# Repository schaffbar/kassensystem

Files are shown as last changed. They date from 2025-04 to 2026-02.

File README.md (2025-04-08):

# Kassensystem

## Projektbeschreibung

Dies ist die Geschichte für die Entwicklung eines Abrechnungssystems für die SchaffBar,
einer offenen Werkstatt. Es sollen die Anwesenheiten der Besucher als die Nutzungszeiten
für ausgewählte elektrische Geräte zu Abrechnungszwecken erfasst werden.

Mittels eines RFID-Tags, das dem Besucher ausgehändigt wird, bei der Registrierung an der Theke,
wird beim Betreten und Verlassen des Werkstattbereichs ein Zeitpaar bestimmt,
das zur Abrechnung im Kassensystem herangezogen wird.
An einem Gerät kann mittels des RFID-Tags und einem WLan-Relais die Versorgungsspannung
eines Gerätes ein und ausgeschlatet werden und damit ebenfalls ein weiteres Zeitpaar
erstellt werden, das zur Abrechnung verwendet werden kann.

Das Lesen der RFID-Tags kann mittels eines RFID-Lesers erfolgen,
während die Daten in einer Datenbank auf einem Server gespeichert werden.

Daraus ergibt sich für das System folgende Aufteilung
- rfidReader - Bereitstellung des RFID-Tags an unterschiedlichen Positionen
- Comm Edge Device (TimeMachine) - Software auf dem Server dient als Schnittstelle zum Datenbanksystem
- ein Kassensystem

Als Kassensystem wird aktuell mit einer Offline Version von Odoo gearbeitet,
diese läuft in einem Docker-Container, in einem weiteren Container befindet sich die Datenbank,
ein weiteren Container wird es für die TimeMachine-Software geben.

## rfidReader

An folgenden oben beschriebenen Position kann ein RFID-Reader zur Anwendung kommen.
- dem Tresen
- dem Eingangsbereich zur Werkstatt
- an einem elektrischem Gerät "Gerätekontrolle"
diese Anwendungsfälle werden im weiteren Verlauf auch UseCases genannt.

Aktuell wird die ArduinoIDE zur Entwicklung verwendet, um aber die verwendeten Bibliotheken mitzuliefern
soll die Entwicklung auf PlatformIO umgestellt werden.
Auch soll die LVGL Bibliothek zukünftig verwendet werden, damit später das Handling von Schaltflächen und
anderem leichter implementiert werden kann.

### Hardwarebeschreibung

Eine Mikroprozessorsystem soll folgende Hardwaremerkmale aufweisen.
- ein Mikroprozessor mit einer WLan-Schnittstelle zur Kommunikation mit dem Server und den Datenbanken,
- einem RFID-Modul zum Lesen der ID-Nummer
- ein Display zur Darstellung von Informationen an den Benutzer,
   beziehungsweise Interaktion über die Touch-Funktionalität.

### Softwarebeschreibung

### Konfigurationsdaten

Um den Konfigurationsaufwand gering zuhalten wird beim Start des RFID-Readers die MAC-Adresse an den Server gesendet,
und anhand der Einträge in der Datenbank werden die Konfigurationsdaten an den RFID-Reader übertragen.

#### Tresen

Nach dem Auflegen des RFID-Tags auf dem RFID-Reader wird diese an den Server übertragen und in einer Datensatz der Datenbank abgelegt und steht zur weiteren Verarbeitung am Tresen zur Verfügung, wie Bearbeitung der Besucherdaten, zur Abrechnung, oder ...
Am Tresen erfolgt die Zuordnung des RFID-Tags zu einem Besucher

#### Eingangsbereich

Durch die Registrierung des Besuchers an der Theke hat dieser einen RFID-Tag erhalten, im Anschluss kann er seine Sachen richten, die er mit in den Werkstattbereich nehmen möchte. Beim Betreten und Verlassen des Werkstattbereichs hält der Besucher sein RFID-Tag an den RFID-Leser zur Erstellung einer Zeitmarke, die Differenz der Zeitspanne entspricht der Nutzungsdauer zur Abrechung. In Abhängigkeit der vorhandenen Datenbankeinträge ergibt sich das Betreten bzw. Verlassen der Werkstatt. Zur Berücksichtigung von Pausen oder ähnlichem können in der Datenbank mehrere Zeitpaare
eines Besuchers angelegt werden.

#### Gerätekontrolle

In den Stammdaten eines Besuchers ist hinterlegt, ob für einen Kunden die jeweilige Unterweisung für das Gerät erfolgt ist,
damit kann die unberechtige Verwendung von Geräten verhindert und die Unfallgefahr reduziert werden.
Nur wenn die Unterweisung hinterlegt ist, darf die Versorgungsspannung eingeschaltet werden, auch hier erfolgt die Abfrage
über die die Software auf dem Server.

## Comm Edge Device --Namensfindung

Diese Software bildet das Bindeglied zwischen den RFID-Reader und der Datenbank,
in Abhängigkeit des UseCases und dem Ergebnis der Datenbankabfrage wird die entsprechende Ausgabe auf dem RFID-Reader gessteuert.

## Kassensystem-SW

Aktuell soll eine offline Version von Odoo als Kassensystem verwendet werden,
da hier viele Funktionen bereits vorhanden sind.
Die Kopplung der RFID-Reader an das Kassensystem sowie die Auswertung der zusätzlichen Informationen
aus den hinzugefügten Tabellen muss noch erfolgen.

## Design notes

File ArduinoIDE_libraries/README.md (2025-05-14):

# Compilation der rfidReader SW mit der Arduino IDE

Hier werden einige Schritte genannt um die Software der rfidReader mittels der Arduino IDE 
zu übersetzen und auf den Prozessor zu flashen

## Installation der Arduino IDE

Die Ardunio IDE kann unter dem genannten Link für veschiedene Betriebssystem heruntergeladen werden.
https://www.arduino.cc/en/software/

## Verwendung des ESP32 in der Arduino IDE

Um ESP32 Prozessoren in der Arduino ESP nutzen zu können, sind die Schritte von einer der 
Anleitungen hinter den folgenden Links abzuarbeiten.

https://randomnerdtutorials.com/installing-esp32-arduino-ide-2-0/

https://randomnerdtutorials.com/installing-the-esp32-board-in-arduino-ide-windows-instructions/

## Bereitstellung der verwendeten Bibliotheken

Um die hier verwendeten Bibliotheken mit den zugehörigen weiteren Abhängigkeiten
nicht mühsam einzeln suchen zu müssen werden diese hier bereit gestellt.

Wenn man die Arduino IDE startet kann man unter dem Menüpunkt "File/ Preferences" 
das Fenster für die Einstellungen öffnen. Hinter dem Eintrag unter "Sketchbook location"
gibt es einen Ordner libraries, in diesen sind die hier abgelegten Bibliotheken zu kopieren

## Einstellungen

Unter dem Menüeintrag "Tools/Board" öffnet sich ein Menü, hier ist der Eintrag "ESP32C3 Dev Module" auszuwählen.
Für das Flashen und die Einstellungen der seriellen Schnittstelle ist der Menüeintrag "Port" zu wählen.

## Datum
Diese Datei mit den genannten Links wurde am 09.05.2025 erstellt.

## Sonstiges
Die jeweiligen Nutzungsbdingungen sind unter den originalen Ablageorten zu finden.

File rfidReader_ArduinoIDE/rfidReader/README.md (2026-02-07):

# Setup
## Arduino IDE
- Folge dieser Anleitung um die ESP Platform in der Arduino IDE zu aktivieren: https://docs.espressif.com/projects/arduino-esp32/en/latest/installing.html
- Installiere die fehlenden Bibliotheken.
- Board: ESP32C3
- USB CDC On Boot: Enabled
  (ansonsten funktioniert die Ausgabe der seriellen Schnittstelle nicht.)

## Visial Studio Code
- Im Visual Studio das PlatformIO plugin installieren
- platform.ini muß folgende Zeile enthalten, sonst funktioniert die serielle Konsole nicht.
```
build_flags = -DCORE_DEBUG_LEVEL=0 -DARDUINO_USB_MODE -DARDUINO_USB_CDC_ON_BOOT=1
```
- Installiere die fehlenden Bibliotheken.

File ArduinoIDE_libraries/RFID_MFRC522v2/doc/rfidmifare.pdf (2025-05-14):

## Using a MFRC522 reader to read and write MIFARE RFID cards

on ARDUINO through the MFRC522 library BY COOQROBOT.
Mario Capurso (m.capurso@libero.it)

MIFARE is the NXP Semiconductors-owned trademark of a series of chips widely
used in contactless smart cards and proximity cards. According to the producers, billions of smart card chips and many millions of reader modules have been sold. [1]

The technology is owned by NXP Semiconductors (spin off from Philips Electronics in 2006) with headquarters in Eindhoven, Netherlands, and main business sites in Nijmegen, Netherlands, and Hamburg, Germany.

The MIFARE name covers proprietary technologies based upon various levels of the ISO/IEC 14443 Type A 13.56 MHz contactless smart card standard.
The MIFARE name (derived from the term MIkron FARE Collection System) covers
seven different kinds of contactless cards.

MIFARE Classic employs a proprietary protocol compliant to parts (but not all) of ISO/IEC 14443-3 Type A, with an NXP proprietary security protocol for authentication and ciphering.

The MIFARE Classic card is fundamentally just a memory storage device, where the memory is divided into segments and blocks with simple security mechanisms for access control. They are ASIC-based and have limited computational power. Thanks
to their reliability and low cost, those cards are widely used for electronic wallet, access control, corporate ID cards, transportation or stadium ticketing.

The MIFARE Classic 1K offers 1024 bytes of data storage, split into 16 sectors; each sector is protected by two different keys, called A and B. Each key can be programmed to allow operations such as reading, writing, increasing valueblocks, etc. MIFARE Classic 4K offers 4096 bytes split into forty sectors, of which 32 are same size as in the 1K with eight more that are quadruple size sectors. MIFARE Classic mini offers 320 bytes split into five sectors.

For each of these card types, 16 bytes per sector are reserved for the keys and access conditions and can not normally be used for user data. Also, the very first 16 bytes contain the serial number of the card and certain other manufacturer data and are read only. That brings the net storage capacity of these cards down to 752 bytes for MIFARE Classic 1k, 3440 bytes for MIFARE Classic 4k, and 224 bytes for Mini. It uses an NXP proprietary security protocol (Crypto-1) for authentication and ciphering.

The encryption used by the MIFARE Classic card uses a 48 bit key. [18]
A presentation by Henryk Plötz and Karsten Nohl[19] at the Chaos Communication Congress in December 2007 described a partial reverse-engineering of the algorithm used in the MIFARE Classic chip. Abstract and slides[20] are available online. A paper that describes the process of reverse engineering this chip was published at the August 2008 USENIX security conference.[21] (https://www.usenix.org/legacy/events/sec08/tech/full_papers/nohl/nohl.pdf)

In March 2008 the Digital Security[22] research group of the Radboud University Nijmegen made public that they performed a complete reverse-engineering and
were able to clone and manipulate the contents of an OV-Chipkaart which is a MIFARE Classic card.[23] (http://www.cs.ru.nl/~flaviog/publications/Talk.Mifare.pdf) For demonstration they used the Proxmark device, a 125 kHz / 13.56 MHz research instrument.[24] The schematics and software are released under the free GNU General Public License by Jonathan Westhues in 2007. They demonstrate it is even possible to perform card-only attacks using just an ordinary stock-commercial NFC reader in combination with the libnfc library.

In April 2009 new and better card-only attack on MIFARE Classic has been
found. It was first announced at the Rump session of Eurocrypt 2009.[35] This attack was presented at SECRYPT 2009.[36] The full description of this latest and fastest attack to date can also be found in the IACR preprint archive.[37] The new attack improves by a factor of more than 10 all previous card-only attacks on MIFARE Classic, has instant running time, and it does not require a costly precomputation.

The new attack allows to recover the secret key of any sector of MIFARE Classic card via wireless interaction, within about 300 queries to the card. It can then be combined with the nested authentication attack in the Nijmegen Oakland paper to recover subsequent keys almost instantly. Both attacks combined and with the right hardware equipment such as Proxmark3, one should be able to clone any MIFARE Classic card in not more than 10 seconds. This is much faster than previously thought.

The MFRC522 is a highly integrated reader/writer IC for contactless communication at 13.56 MHz. The MFRC522 reader supports ISO/IEC 14443 A/MIFARE mode.
The MFRC522’s internal transmitter is able to drive a reader/writer antenna designed to communicate with ISO/IEC 14443 A/MIFARE cards and transponders without additional active circuitry. The receiver module provides a robust and efficient implementation for demodulating and decoding signals from ISO/IEC 14443 A/MIFARE compatible cards and transponders. The digital module manages the complete ISO/IEC 14443 A framing and error detection (parity and CRC) functionality.

The MFRC522 supports all variants of the MIFARE Mini, MIFARE 1K, MIFARE 4K, MIFARE Ultralight, MIFARE DESFire EV1 and MIFARE Plus RF identification protocols. To aid readability throughout this data sheet, the MIFARE Mini,

MIFARE 1K, MIFARE 4K, MIFARE Ultralight, MIFARE DESFire EV1 and MIFARE Plus products and protocols have the generic name MIFARE.

The following host interfaces are provided:

- Serial Peripheral Interface (SPI)
- Serial UART (similar to RS232 with voltage levels dependant on pin voltage supply)
- I2C-bus interface


Answer to Request :

With the Answer to Request sequence the MIFARE® RWD (Read Write Device) requests all MIFARE® cards in the antenna field. When a card is in the operating range of a RWD, the RWD continues communication with the appropriate protocol.

Anticollision loop
In the Anticollision loop the serial number of the card is read. If there are several cards in the operating range of a RWD they can be distinguished by their different serial numbers and one can be selected (Select card) for further transactions. The unselected cards return to the standby mode and wait for a new Answer to Request and Anticollision loop.

Select Card
With the Select Card command the RWD selects one individual card for further authentication and memory related operations. The card returns the Answer to Select (ATS) code, which determines the individual type of the selected card.

Access Specification
After identification and selection of one card the RWD specifies the memory location of the following access.

Three Pass Authentication
The appropriate access key for the previously specified access is used for 3 Pass Authentication. Any communication after authentication is automatically encrypted at the sender and decrypted by the receiver.

Read/Write

After authentication any of the following operations may be performed:

READ | reads one block
WRITE | writes one block
DECREMENT | decrements the contents of one block and stores the result
| in the data-register
INCREMENT | increments the contents of one block and stores the result
| in the data-register
TRANSFER | writes the contents of the data-register to one block
RESTORE | stores the contents of one block in the data-register

The MF1ICS50 IC of a Mifare Classic has integrated a 8192 Bit EEPROM which is split into 16 sectors with 4 blocks. One block consists of 16 bytes (1 Byte = 8 Bit).


Manufacturer Code (Block 0 of Sector 0)

The first block of the memory is reserved for manufacturer data like 32 bit serial number. This is a read only block. In many documents it is named "Block 0".

Data Block (Block 0 to 3 except "Block 0")

Access conditions for the Data Blocks are defined in the Sector Trailers. According to these conditions data can be read, written, incremented, decremented, transferred or restored either with Key A, Key B or never.

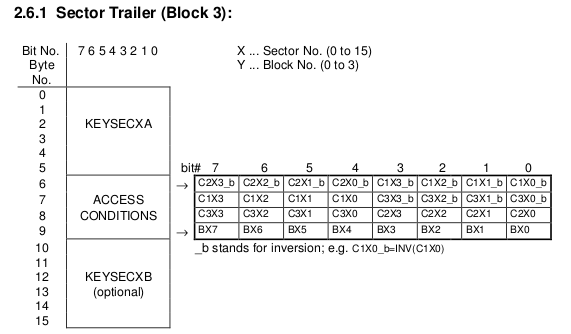
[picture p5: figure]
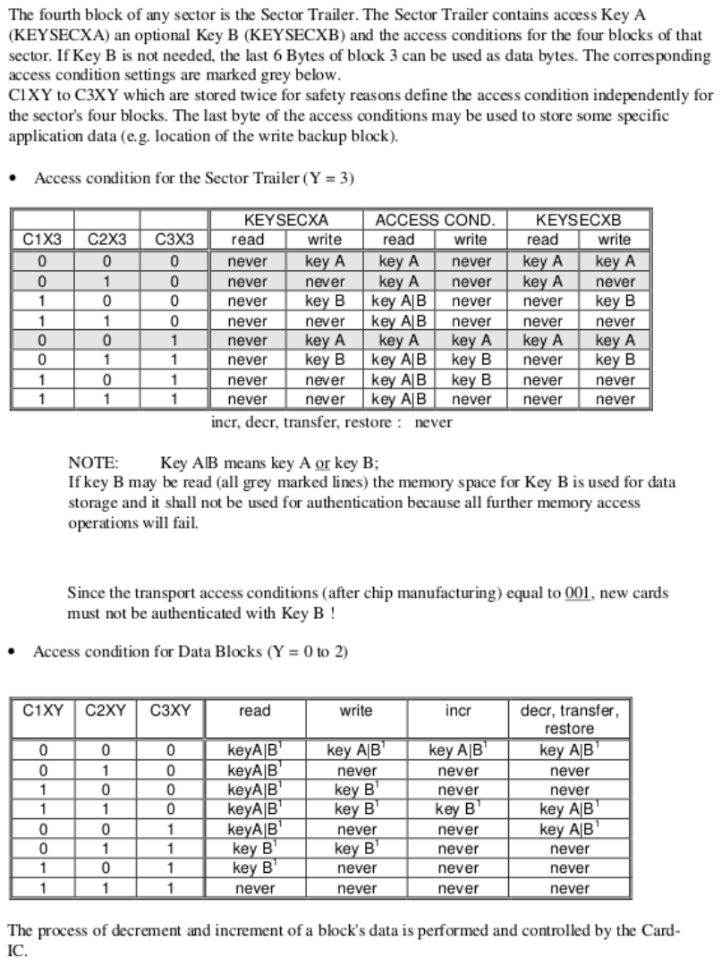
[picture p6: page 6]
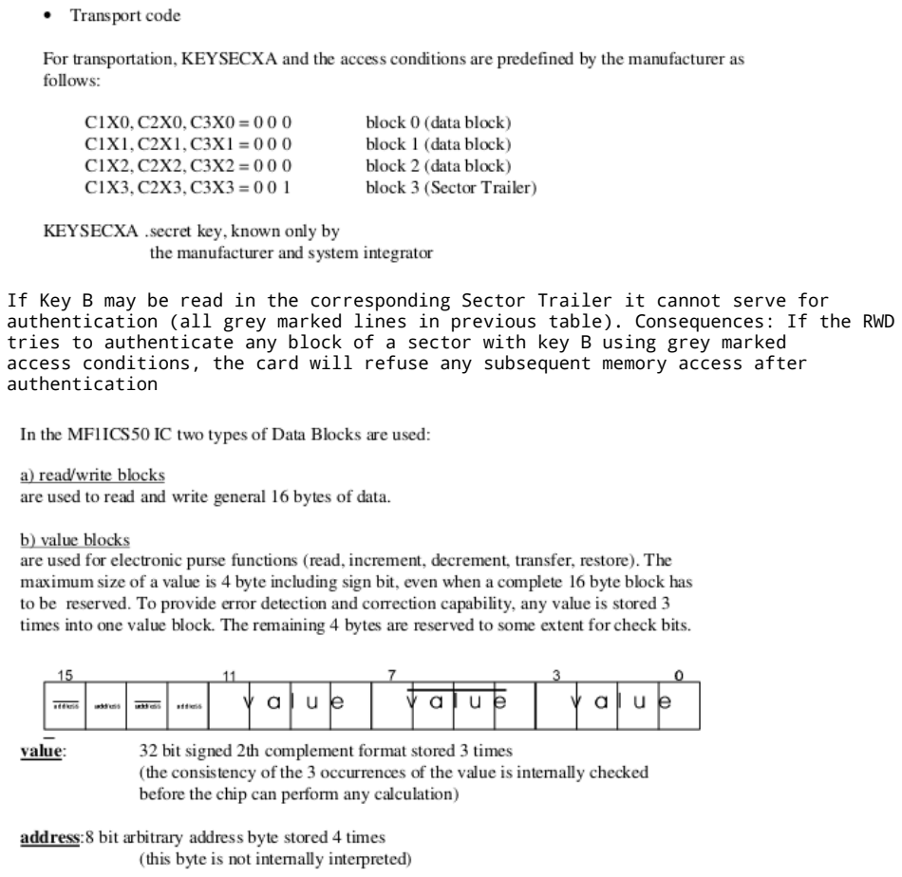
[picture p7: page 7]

If Key B may be read in the corresponding Sector Trailer it cannot serve for authentication (all grey marked lines in previous table). Consequences: If the RWD tries to authenticate any block of a sector with key B using grey marked
access conditions, the card will refuse any subsequent memory access after authentication

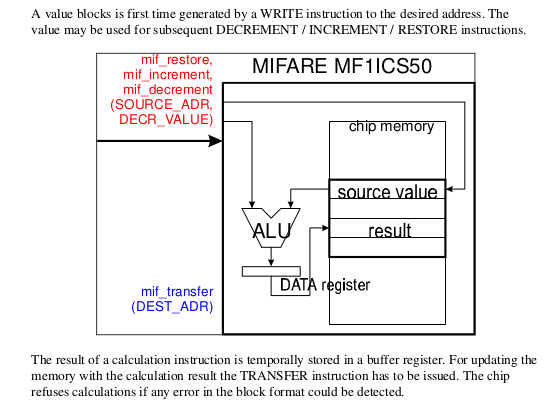
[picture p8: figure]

The described memory organization makes it possible to appoint different sectors to different applications and to prevent data corruption by using application specific secret keys. Keys can only be altered by a RWD which has stored the actual Key A or Key B if this is allowed according to access conditions. Otherwise the actual key cannot be changed anymore.

Before the execution of a command the correct format of the Access Conditions is checked by the Card-IC. Thus, when programming the Sector Trailer the card needs to be fixed within the operating range of a RWD's antenna to prevent interruption of the write operation because any unsuccessful write operation may lead to blocking the whole sector.

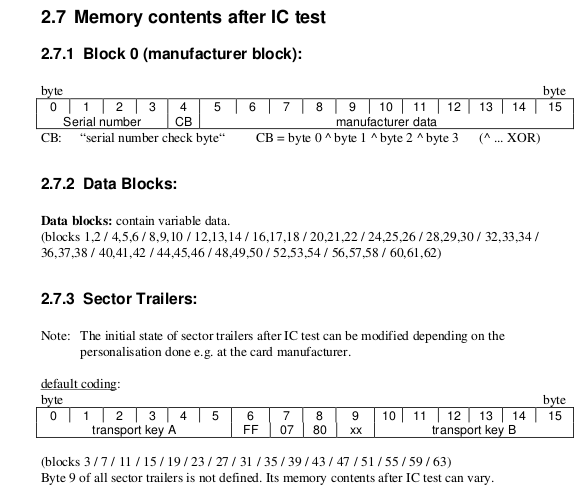
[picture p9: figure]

## MFRC522.h – A Library to use ARDUINO RFID MODULE KIT 13.56

MHZ BY COOQROBOT.

There are three hardware components involved:

1) The micro controller: An Arduino
2) The PCD (Proximity Coupling Device): NXP MFRC522 Contactless Reader IC
3) The PICC (short for Proximity Integrated Circuit Card): A card or tag using the ISO 14443A interface, eg Mifare or NTAG203.

MIFARE Classic 1K (MF1S503x):

Has 16 sectors * 4 blocks/sector * 16 bytes/block = 1024 bytes. The blocks are numbered 0-63.

Block 3 in each sector is the Sector Trailer.
* | Bytes 0-5: | Key A
* | Bytes 6-8: | Access Bits
* | Bytes 9: | User data
* | Bytes 10-15: Key B (or user data)

Block 0 is read only manufacturer data.

To access a block, an authentication using a key from the block's sector must be performed first.

Example: To read from block 10, first authenticate using a key from sector 3 (blocks 8-11).

All keys are set to FFFFFFFFFFFFh at chip delivery.

Warning: Please read section 8.7 "Memory Access". It includes this text: if the PICC detects a format violation the whole sector is irreversibly blocked.

To use a block in "value block" mode (for Increment/Decrement operations) you need to change the sector trailer. Use PICC_SetAccessBits() to calculate the bit patterns.

Commands sent to the PICC.

The commands used by the PCD to manage communication with several PICCs (ISO 14443-3, Type A, section 6.4)

PICC_CMD_REQA = 0x26,
REQuest command, Type A. Invites PICCs in state IDLE to go to READY and prepare for anticollision or selection. 7 bit frame.
PICC_CMD_WUPA = 0x52,
Wake-UP command, Type A. Invites PICCs in state IDLE and HALT to go to READY(*) and prepare for anticollision or selection. 7 bit frame.
PICC_CMD_CT = 0x88,
Cascade Tag. Not really a command, but used during anti collision. PICC_CMD_SEL_CL1 = 0x93,
Anti collision/Select, Cascade Level 1
PICC_CMD_SEL_CL2 = 0x95,
Anti collision/Select, Cascade Level 2 PICC_CMD_SEL_CL3 = 0x97,
Anti collision/Select, Cascade Level 3
PICC_CMD_HLTA = 0x50,
HaLT command, Type A. Instructs an ACTIVE PICC to go to state HALT.

The commands used for MIFARE Classic
Use PCD_MFAuthent to authenticate access to a sector, then use these commands to read/write/modify the blocks on the sector.
The read/write commands can also be used for MIFARE Ultralight.

PICC_CMD_MF_AUTH_KEY_A = 0x60,
Perform authentication with Key A
PICC_CMD_MF_AUTH_KEY_B = 0x61,
Perform authentication with Key B
PICC_CMD_MF_READ | = 0x30,
Reads one 16 byte block from the authenticated sector of the PICC. Also used for MIFARE Ultralight.
PICC_CMD_MF_WRITE | = 0xA0,
Writes one 16 byte block to the authenticated sector of the PICC. Called "COMPATIBILITY WRITE" for MIFARE Ultralight.
PICC_CMD_MF_DECREMENT = 0xC0,
Decrements the contents of a block and stores the result in the internal data register.
PICC_CMD_MF_INCREMENT = 0xC1,
Increments the contents of a block and stores the result in the internal data register.
PICC_CMD_MF_RESTORE | = 0xC2,
Reads the contents of a block into the internal data register. PICC_CMD_MF_TRANSFER = 0xB0,
Writes the contents of the internal data register to a block.

List of the functions in the library

Functions for setting up the Arduino

MFRC522(byte chipSelectPin, byte resetPowerDownPin);
void setSPIConfig();

Basic interface functions for communicating with the MFRC522

void PCD_WriteRegister(byte reg, byte value);
void PCD_WriteRegister(byte reg, byte count, byte *values);
byte PCD_ReadRegister(byte reg);
void PCD_ReadRegister(byte reg, byte count, byte *values, byte rxAlign = 0); void setBitMask(unsigned char reg, unsigned char mask);
void PCD_SetRegisterBitMask(byte reg, byte mask);
void PCD_ClearRegisterBitMask(byte reg, byte mask);
byte PCD_CalculateCRC(byte *data, byte length, byte *result);

Functions for manipulating the MFRC522

void PCD_Init();
void PCD_Reset();
void PCD_AntennaOn();

Functions for communicating with PICCs

byte PCD_TransceiveData(byte *sendData, byte sendLen, byte *backData, byte *backLen, byte *validBits = NULL, byte rxAlign = 0, bool checkCRC = false);

byte PCD_CommunicateWithPICC(byte command, byte waitIRq, byte *sendData, byte sendLen, byte *backData = NULL, byte *backLen = NULL, byte *validBits = NULL, byte rxAlign = 0, bool checkCRC = false);

byte PICC_RequestA(byte *bufferATQA, byte *bufferSize);
byte PICC_WakeupA(byte *bufferATQA, byte *bufferSize);
byte PICC_REQA_or_WUPA( byte command, byte *bufferATQA, byte *bufferSize); byte PICC_Select(Uid *uid, byte validBits = 0);
byte PICC_HaltA();

Functions for communicating with MIFARE PICCs

byte PCD_Authenticate(byte command, byte blockAddr, MIFARE_Key *key, Uid *uid); void PCD_StopCrypto1();
byte MIFARE_Read(byte blockAddr, byte *buffer, byte *bufferSize);
byte MIFARE_Write(byte blockAddr, byte *buffer, byte bufferSize);
byte MIFARE_Decrement(byte blockAddr, long delta);
byte MIFARE_Increment(byte blockAddr, long delta);
byte MIFARE_Restore(byte blockAddr);
byte MIFARE_Transfer(byte blockAddr);
byte MIFARE_Ultralight_Write(byte page, byte *buffer, byte bufferSize);

Support functions

byte PCD_MIFARE_Transceive( byte *sendData, byte sendLen, bool acceptTimeout = false);
const char *GetStatusCodeName(byte code);
byte PICC_GetType(byte sak);
const char *PICC_GetTypeName(byte type);
void PICC_DumpToSerial(Uid *uid);
void PICC_DumpMifareClassicToSerial(Uid *uid, byte piccType, MIFARE_Key *key);
void PICC_DumpMifareClassicSectorToSerial(Uid *uid, MIFARE_Key *key, byte sector); void PICC_DumpMifareUltralightToSerial();
void MIFARE_SetAccessBits(byte *accessBitBuffer, byte g0, byte g1, byte g2, byte g3);

Convenience functions - does not add extra functionality

bool PICC_IsNewCardPresent();
bool PICC_ReadCardSerial();

Detailed documentation – enum and structures

PICC types we can detect. Remember to update PICC_GetTypeName() if you add more.

enum PICC_Type

Return codes from the functions in this class. Remember to update GetStatusCodeName() if you add more.

enum StatusCode

A struct used for passing the UID of a PICC.

typedef struct {
byte | size; | Number of bytes in the UID. 4, 7 or 10.
byte | uidByte[10];
byte | sak; | The SAK (Select acknowledge) byte returned
| | from the PICC after successful selection.
} Uid

A struct used for passing a MIFARE Crypto1 key

typedef struct {
byte | keyByte[MF_KEY_SIZE];
} MIFARE_Key;

Example:
// Prepare key - all keys are set to FFFFFFFFFFFFh at chip delivery from the factory. MFRC522::MIFARE_Key key;
for (byte i = 0; i < 6; i++) key.keyByte[i] = 0xFF;

Member variables

Uid uid; | Used by PICC_ReadCardSerial().

Detailed documentation – functions

+Create object instance
MFRC522(
byte chipSelectPin, Arduino pin used for SPI chip select byte resetPowerDownPin Arduino pin used for SPI reset
);
Example:
#include <SPI.h>

#include <MFRC522.h>

#define SS_PIN 10 //Arduino Uno

#define RST_PIN 9

MFRC522 mfrc522(SS_PIN, RST_PIN); | // Create MFRC522 instance.

+Initializes the MFRC522 chip.
void MFRC522::PCD_Init()
Example:
void setup() {
Serial.begin(9600); | // Init serial communications with PC
SPI.begin(); | // Init SPI bus
mfrc522.PCD_Init(); | // Init MFRC522 card
}

+Set SPI bus to work with MFRC522 chip.

Please call this function if you have changed the SPI config since the MFRC522 constructor was run.

void MFRC522::setSPIConfig()

+Performs a soft reset on the MFRC522 chip and waits for it to be ready again. void MFRC522::PCD_Reset()

+Turns the antenna on by enabling pins TX1 and TX2.
After a reset these pins are disabled.
void MFRC522::PCD_AntennaOn()

+Transmits a REQuest command, Type A. Invites PICCs in state IDLE to go to READY and prepare for anticollision or selection. 7 bit frame.
Beware: When two PICCs are in the field at the same time I often get STATUS_TIMEOUT -probably due do bad antenna design.
return STATUS_OK on success, STATUS_??? otherwise.
byte MFRC522::PICC_RequestA(
byte *bufferATQA, The buffer to store the ATQA (Answer to request) in
byte *bufferSize Buffer size, at least two bytes. Also number of bytes returned if STATUS_OK.

+Transmits a Wake-UP command, Type A. Invites PICCs in state IDLE and HALT to go to READY(*) and prepare for anticollision or selection. 7 bit frame.
Beware: When two PICCs are in the field at the same time I often get STATUS_TIMEOUT -probably due do bad antenna design.
return STATUS_OK on success, STATUS_??? otherwise.
byte MFRC522::PICC_WakeupA(
byte *bufferATQA, The buffer to store the ATQA (Answer to request) in
byte *bufferSize Buffer size, at least two bytes. Also number of bytes returned if STATUS_OK.

+Transmits SELECT/ANTICOLLISION commands to select a single PICC.
Before calling this function the PICCs must be placed in the READY(*) state by calling PICC_RequestA() or PICC_WakeupA().
On success:

-The chosen PICC is in state ACTIVE(*) and all other PICCs have returned to state IDLE/HALT. (Figure 7 of the ISO/IEC 14443-3 draft.)
-The UID size and value of the chosen PICC is returned in *uid along with the SAK.

A PICC UID consists of 4, 7 or 10 bytes.
Only 4 bytes can be specified in a SELECT command, so for the longer UIDs two or three iterations are used:
UID size | Number of UID bytes | Cascade levels | Example of PICC
======== | =================== | ============== | ===============
single | 4 | 1 | MIFARE Classic
double | 7 | 2 | MIFARE Ultralight
triple | 10 | 3 | Not currently in use?

return STATUS_OK on success, STATUS_??? otherwise.
byte MFRC522::PICC_Select(
Uid *uid, | Pointer to Uid struct. Normally output, but can also
be used to supply a known UID.
byte validBits | The number of known UID bits supplied in *uid.

Normally 0. If set you must also supply uid->size.

Description of buffer structure:

Byte 0: SEL | Indicates the Cascade Level: PICC_CMD_SEL_CL1,
PICC_CMD_SEL_CL2 or PICC_CMD_SEL_CL3
Byte 1: NVB | Number of Valid Bits (in complete command, not just the UID):
High nibble: complete bytes, Low nibble: Extra bits.
Byte 2: UID-data or CT See explanation below. CT means Cascade Tag.
Byte 3: UID-data
Byte 4: UID-data
Byte 5: UID-data
Byte 6: BCC | Block Check Character - XOR of bytes 2-5
Byte 7: CRC_A
Byte 8: CRC_A

The BCC and CRC_A is only transmitted if we know all the UID bits of the current Cascade Level.
Description of bytes 2-5: (Section 6.5.4 of the ISO/IEC 14443-3 draft: UID contents and cascade levels)
UID size | Cascade level | Byte2 Byte3 Byte4 Byte5
======== | ============= | ===== ===== ===== =====
4 bytes | 1 | uid0 uid1 uid2 uid3

7 bytes | 1 | CT | uid0 uid1 uid2
2 | uid3 uid4 uid5 uid6
10 bytes | 1 | CT | uid0 uid1 uid2
| 2 | CT | uid3 uid4 uid5

+Instructs a PICC in state ACTIVE(*) to go to state HALT. return STATUS_OK on success, STATUS_??? otherwise.
byte PICC_HaltA();
Example:
// Halt PICC
mfrc522.PICC_HaltA();

+Executes the MFRC522 MFAuthent command.
This command manages MIFARE authentication to enable a secure communication to any MIFARE Mini, MIFARE 1K and MIFARE 4K card.
The authentication is described in the MFRC522 datasheet section 10.3.1.9 and http://www.nxp.com/documents/data_sheet/MF1S503x.pdf section 10.1. for use with MIFARE Classic PICCs.
The PICC must be selected - ie in state ACTIVE(*) - before calling this function. Remember to call PCD_StopCrypto1() at the end of communication with the authenticated PICC - otherwise no new communications can start.
All keys are set to FFFFFFFFFFFFh at chip delivery.
return STATUS_OK on success, STATUS_??? otherwise. Probably STATUS_TIMEOUT if you supply the wrong key.
byte MFRC522::PCD_AuthenticateI(
byte command, | PICC_CMD_MF_AUTH_KEY_A or PICC_CMD_MF_AUTH_KEY_B
byte blockAddr, | The block number. See numbering in the comments in
| the .h file.
MIFARE_Key *key, | Pointer to the Crypto1 key to use (6 bytes)
Uid *uid | Pointer to Uid struct. The first 4 bytes of the UID
| is used.
)
Example:
MFRC522::MIFARE_Key key;
for (byte i = 0; i < 6; i++) key.keyByte[i] = 0xFF; byte trailerBlock = 7;
byte status;
if ( ! mfrc522.PICC_ReadCardSerial()) return;
status = mfrc522.PCD_Authenticate(MFRC522::PICC_CMD_MF_AUTH_KEY_A, trailerBlock, &key, &(mfrc522.uid));
if (status != MFRC522::STATUS_OK) {
Serial.print("PCD_Authenticate() failed: "); Serial.println(mfrc522.GetStatusCodeName(status)); return;
}

+Used to exit the PCD from its authenticated state.
Remember to call PCD_StopCrypto1() at the end of communication with the authenticated PICC - otherwise no new communications can start.
void MFRC522::PCD_StopCrypto1()
Example:
// Stop encryption on PCD
mfrc522.PCD_StopCrypto1();

+Reads 16 bytes (+ 2 bytes CRC_A) from the active PICC.
For MIFARE Classic the sector containing the block must be authenticated before calling this function.
For MIFARE Ultralight only addresses 00h to 0Fh are decoded.
* The MF0ICU1 returns a NAK for higher addresses.

* The MF0ICU1 responds to the READ command by sending 16 bytes starting from
the page address defined by the command argument.
* For example; if blockAddr is 03h then pages 03h, 04h, 05h, 06h are returned.
* A roll-back is implemented: If blockAddr is 0Eh, then the contents of pages 0Eh, 0Fh, 00h and 01h are returned.
The buffer must be at least 18 bytes because a CRC_A is also returned.
Checks the CRC_A before returning STATUS_OK.
return STATUS_OK on success, STATUS_??? otherwise.
byte MFRC522::MIFARE_Read(
byte blockAddr, | MIFARE Classic: The block (0-0xff) number.
| MIFARE Ultralight: The first page to return data from.
byte *buffer, | The buffer to store the data in

byte *bufferSize Buffer size, at least 18 bytes. Also number of bytes returned
| if STATUS_OK.
Example:
byte valueBlockA = 4; byte buffer[18]; byte size = sizeof(buffer);
byte status = mfrc522.MIFARE_Read(valueBlockA, buffer, &size);

+Writes 16 bytes to the active PICC.
For MIFARE Classic the sector containing the block must be authenticated before calling this function.
For MIFARE Ultralight the operation is called "COMPATIBILITY WRITE".
Even though 16 bytes are transferred to the Ultralight PICC, only the least significant 4 bytes (bytes 0 to 3) are written to the specified address. It is recommended to set the remaining bytes 04h to 0Fh to all logic 0.
return STATUS_OK on success, STATUS_??? otherwise.
byte MFRC522::MIFARE_Write(
byte blockAddr,
| MIFARE Classic: The block (0-0xff) number.
| MIFARE Ultralight: The page (2-15) to write to.
byte *buffer, | The 16 bytes to write to the PICC
byte bufferSize | Buffer size, must be at least 16 bytes. Exactly 16 bytes are
| written.
Example:
byte valueBlockA = 4;
byte value1Block[] = { 1,2,3,4, 5,6,7,8, 9,10,255,12, 13,14,15,16}; status = mfrc522.MIFARE_Write(valueBlockA, value1Block, 16);
if (status != MFRC522::STATUS_OK) {
Serial.print("MIFARE_Write() failed: "); Serial.println(mfrc522.GetStatusCodeName(status));
}

+MIFARE Decrement subtracts the delta from the value of the addressed block, and stores the result in a volatile memory.
For MIFARE Classic only. The sector containing the block must be authenticated before calling this function.
Only for blocks in "value block" mode, ie with access bits [C1 C2 C3] = [110] or [001].
Use MIFARE_Transfer() to store the result in a block.
return STATUS_OK on success, STATUS_??? otherwise.
byte MFRC522::MIFARE_Decrement(
byte blockAddr, | The block (0-0xff) number.
long delta | This number is subtracted from the value of block blockAddr.

+MIFARE Increment adds the delta to the value of the addressed block, and stores the result in a volatile memory.
For MIFARE Classic only. The sector containing the block must be authenticated before calling this function.
Only for blocks in "value block" mode, ie with access bits [C1 C2 C3] = [110] or

[001].
Use MIFARE_Transfer() to store the result in a block. return STATUS_OK on success, STATUS_??? otherwise.
byte MFRC522::MIFARE_Increment(
byte blockAddr, | The block (0-0xff) number.
long delta | This number is added to the value of block blockAddr.
Example:
// Add 1 to the value of valueBlockA and store the result in valueBlockA. byte valueBlockA = 5;
Serial.print("Adding 1 to value of block "); Serial.println(valueBlockA); byte status = mfrc522.MIFARE_Increment(valueBlockA, 1);
if (status != MFRC522::STATUS_OK) {
Serial.print("MIFARE_Increment() failed: "); Serial.println(mfrc522.GetStatusCodeName(status)); return;
}
status = mfrc522.MIFARE_Transfer(valueBlockA);
if (status != MFRC522::STATUS_OK) { Serial.print("MIFARE_Transfer() failed: "); Serial.println(mfrc522.GetStatusCodeName(status)); return;
}

+MIFARE Restore copies the value of the addressed block into a volatile memory.
For MIFARE Classic only. The sector containing the block must be authenticated before calling this function.
Only for blocks in "value block" mode, ie with access bits [C1 C2 C3] = [110] or [001].
Use MIFARE_Transfer() to store the result in a block.
return STATUS_OK on success, STATUS_??? otherwise.
byte MFRC522::MIFARE_Restore(
byte blockAddr The block (0-0xff) number.
The datasheet describes Restore as a two step operation, but does not explain what data to transfer in step 2.Doing only a single step does not work, so I chose to transfer 0L in step two.

+Helper function for the two-step MIFARE Classic protocol operations Decrement, Increment and Restore.
return STATUS_OK on success, STATUS_??? otherwise.
byte MFRC522::MIFARE_TwoStepHelper(
byte command, | The command to use
byte blockAddr, | The block (0-0xff) number.
long data | The data to transfer in step 2
)

+MIFARE Transfer writes the value stored in the volatile memory into one MIFARE Classic block.
For MIFARE Classic only. The sector containing the block must be authenticated before calling this function.
Only for blocks in "value block" mode, ie with access bits [C1 C2 C3] = [110] or [001].
return STATUS_OK on success, STATUS_??? otherwise.
byte MFRC522::MIFARE_Transfer(
byte blockAddr The block (0-0xff) number.

+Returns a string pointer to a status code name. const char *MFRC522::GetStatusCodeName(
byte code | One of the StatusCode enums.
code values | return values

STATUS_OK: | "Success."
STATUS_ERROR: | "Error in communication."
STATUS_COLLISION: | "Collision detected."
STATUS_TIMEOUT: | "Timeout in communication."
STATUS_NO_ROOM: | "A buffer is not big enough."
STATUS_INTERNAL_ERROR: "Internal error in the code. Should not happen."
STATUS_INVALID: | "Invalid argument."
STATUS_CRC_WRONG: | "The CRC_A does not match."
STATUS_MIFARE_NACK: | "A MIFARE PICC responded with NAK."
default: | "Unknown error"

Example:
Serial.println(mfrc522.GetStatusCodeName(status));

+Translates the SAK (Select Acknowledge) to a PICC type. return PICC_Type
byte MFRC522::PICC_GetType(
byte sak | The SAK byte returned from PICC_Select().
sak | return value
sak & 0x04 | PICC_TYPE_NOT_COMPLETE
0x09 | PICC_TYPE_MIFARE_MINI
0x08 | PICC_TYPE_MIFARE_1K
0x18 | PICC_TYPE_MIFARE_4K
0x00 | PICC_TYPE_MIFARE_UL
0x10 or 0x11 | PICC_TYPE_MIFARE_PLUS
0x01 | PICC_TYPE_TNP3XXX
sak & 0x20 | PICC_TYPE_ISO_14443_4
sak & 0x40 | PICC_TYPE_ISO_18092
else | PICC_TYPE_UNKNOWN

+Returns a string pointer to the PICC type name. const char *MFRC522::PICC_GetTypeName(
byte piccType | One of the PICC_Type enums.
piccType | return value
PICC_TYPE_ISO_14443_4 | "PICC compliant with ISO/IEC 14443-4"
PICC_TYPE_ISO_18092: | "PICC compliant with ISO/IEC 18092 (NFC)"
PICC_TYPE_MIFARE_MINI | "MIFARE Mini, 320 bytes"
PICC_TYPE_MIFARE_1K | "MIFARE 1KB"
PICC_TYPE_MIFARE_4K | "MIFARE 4KB"
PICC_TYPE_MIFARE_UL | "MIFARE Ultralight or Ultralight C"
PICC_TYPE_MIFARE_PLUS | "MIFARE Plus"
PICC_TYPE_TNP3XXX | "MIFARE TNP3XXX"
PICC_TYPE_NOT_COMPLETE "SAK indicates UID is not complete."
PICC_TYPE_UNKNOWN | "Unknown type”
Example:
Serial.println(mfrc522.PICC_GetTypeName(piccType));

+Dumps debug info about the selected PICC to Serial.
On success the PICC is halted after dumping the data.
For MIFARE Classic the factory default key of 0xFFFFFFFFFFFF is tried. void MFRC522::PICC_DumpToSerial(
Uid *uid Pointer to Uid struct returned from a successful PICC_Select(). Example:
mfrc522.PICC_DumpToSerial(&(mfrc522.uid));

+Dumps memory contents of a sector of a MIFARE Classic PICC.
Uses PCD_Authenticate(), MIFARE_Read() and PCD_StopCrypto1.

Always uses PICC_CMD_MF_AUTH_KEY_A because only Key A can always read the sector trailer access bits.
void MFRC522::PICC_DumpMifareClassicSectorToSerial(
Uid *uid, | Pointer to Uid struct returned from a successful PICC_Select()
MIFARE_Key *key, Key A for the sector.
byte sector | The sector to dump, 0..39.

+Calculates the bit pattern needed for the specified access bits. In the [C1 C2 C3] tuples C1 is MSB (=4) and C3 is LSB (=1).
void MFRC522::MIFARE_SetAccessBits(
byte *accessBitBuffer, Pointer to byte 6, 7 and 8 in the sector trailer.
| Bytes [0..2] will be set.
byte g0, | Access bits [C1 C2 C3] for block 0 (for sectors 0-31) or blocks 0-4 (for sectors 32-39)
byte g1, | Access bits C1 C2 C3] for block 1 (for sectors 0-31) or blocks 5-9 (for sectors 32-39)
byte g2, | Access bits C1 C2 C3] for block 2 (for sectors 0-31) or blocks 10-14 (for sectors 32-39)
byte g3 | Access bits C1 C2 C3] for the sector trailer, block 3 (for sectors 0-31) or block 15 (for sectors 32-39)

The access bits are stored in a peculiar fashion.
There are four groups:

g[3] Access bits for the sector trailer, block 3 (for sectors 0-31) or block 15 (for sectors 32-39)

g[2] Access bits for block 2 (for sectors 0-31) or blocks 10-14 (for sectors 32-39) g[1] Access bits for block 1 (for sectors 0-31) or blocks 5-9 (for sectors 32-39) g[0] Access bits for block 0 (for sectors 0-31) or blocks 0-4 (for sectors 32-39)

Each group has access bits [C1 C2 C3]. In this code C1 is MSB and C3 is LSB.
The four CX bits are stored together in a nibble cx and an inverted nibble cx_. Example:
// Sector trailer that defines blocks 5 and 6 as Value Blocks and enables key B. byte trailerBuffer[] = {255,255,255,255,255,255,0,0,0,0, 255,255,255,255,255,255}; // Keep default keys.
// g1=6(i.e.110) => block 5 value block. Key B write&increment, A or B decrement. // g2=6 => Same thing for block 6.
// g3=3 => Key B must be used to modify the Sector Trailer. Key B becomes valid. mfrc522.MIFARE_SetAccessBits(&trailerBuffer[6], 0, 6, 6, 3);

+Check if a card is present
bool MFRC522::PICC_IsNewCardPresent()
Returns true if a PICC responds to PICC_CMD_REQA.
Only "new" cards in state IDLE are invited. Sleeping cards in state HALT are ignored. Example:
// Look for new cards
if ( ! mfrc522.PICC_IsNewCardPresent()) return;

+Read Card Serial
bool MFRC522::PICC_ReadCardSerial()
Simple wrapper around PICC_Select.
Returns true if a UID could be read.The read UID is available in the class variable uid.
Remember to call PICC_IsNewCardPresent(), PICC_RequestA() or PICC_WakeupA() first. return true if one selected

Now a card is selected. The UID and SAK is in mfrc522.uid. Example:
Serial.print("Card UID:");
for (byte i = 0; i < mfrc522.uid.size; i++) { Serial.print(mfrc522.uid.uidByte[i] < 0x10 ? " 0" : " "); Serial.print(mfrc522.uid.uidByte[i], HEX);
}
// Dump PICC type
byte piccType = mfrc522.PICC_GetType(mfrc522.uid.sak); Serial.print("PICC type: "); Serial.println(mfrc522.PICC_GetTypeName(piccType));
if ( piccType != MFRC522::PICC_TYPE_MIFARE_MINI
&& piccType != MFRC522::PICC_TYPE_MIFARE_1K
&& | piccType != MFRC522::PICC_TYPE_MIFARE_4K) {
Serial.println("This sample only works with MIFARE Classic cards."); return;
}

How to convert a normal block into a value block
Usually a normal block has 000 access bits, while a value block has 110 access bits Example:
byte valueBlockA = 5;
byte valueBlockB = 6;
byte trailerBlock = 7;
// We need a sector trailer with blocks 5 and 6 as Value Blocks and enables key B. byte trailerBuffer[] = { 255,255,255,255,255,255,
| 0,0,0,0,255,255,255,255,255,255}; // Keep default keys.
// g1=6 => block 5 as value block. Key B to write&increment, A or B for decrement. // g2=6 => Same thing for block 6.
// g3=3 => Key B must be used to modify the Sector Trailer. Key B becomes valid. mfrc522.MIFARE_SetAccessBits(&trailerBuffer[6], 0, 6, 6, 3);
byte status = mfrc522.MIFARE_Write(trailerBlock, trailerBuffer, 16);
if (status != MFRC522::STATUS_OK) {
Serial.print("MIFARE_Write() failed: "); Serial.println(mfrc522.GetStatusCodeName(status));
return;
}

How to setup a Value Block with a value set to zero Example:
byte blockAddr=5;
byte valueBlock[] = {0,0,0,0, 255,255,255,255, 0,0,0,0,
| blockAddr,~blockAddr,blockAddr,~blockAddr };
byte status = mfrc522.MIFARE_Write(blockAddr, valueBlock, 16); if (status != MFRC522::STATUS_OK) { Serial.print("MIFARE_Write() failed: "); Serial.println(mfrc522.GetStatusCodeName(status));
}

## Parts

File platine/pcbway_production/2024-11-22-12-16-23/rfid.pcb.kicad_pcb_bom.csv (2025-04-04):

Designator | Quantity | Value | Footprint | Package | MPN | DNP | Mount_Type | Description | MF | MAXIMUM_PACKAGE_HEIGHT | Price | Check_prices | STANDARD | SnapEDA_Link | MP | Description_1 | Availability | MANUFACTURER
5V GND GP3 GP1 | 1 | Conn_01x04_Socket | PinSocket_1x04_P2.54mm_Vertical |  |  |  | tht | Generic connector, single row, 01x04, script generated
ESP32 C3 Super Mini | 1 | ESP32-C3_SUPERMINI | MODULE_ESP32-C3_SUPERMINI | Package |  |  | tht |  | Espressif Systems | 4.2mm | None | https://www.snapeda.com/parts/ESP32-C3%20SuperMini_TH/Espressif+Systems/view-part/?ref=eda | Manufacturer Recommendations | https://www.snapeda.com/parts/ESP32-C3%20SuperMini_TH/Espressif+Systems/view-part/?ref=snap | ESP32-C3 SuperMini_TH | Super tiny ESP32-C3 board | Not in stock | Espressif
J1 | 1 | TFT Adafruit_ILI9341 | PinSocket_1x14_P2.54mm_Vertical |  |  |  | tht | Pin Header female with pin space 2.54mm. Pin Count - 14
J2 | 1 | MFRC522 | PinSocket_1x08_P2.54mm_Vertical |  |  |  | tht | Pin Header female with pin space 2.54mm. Pin Count -8

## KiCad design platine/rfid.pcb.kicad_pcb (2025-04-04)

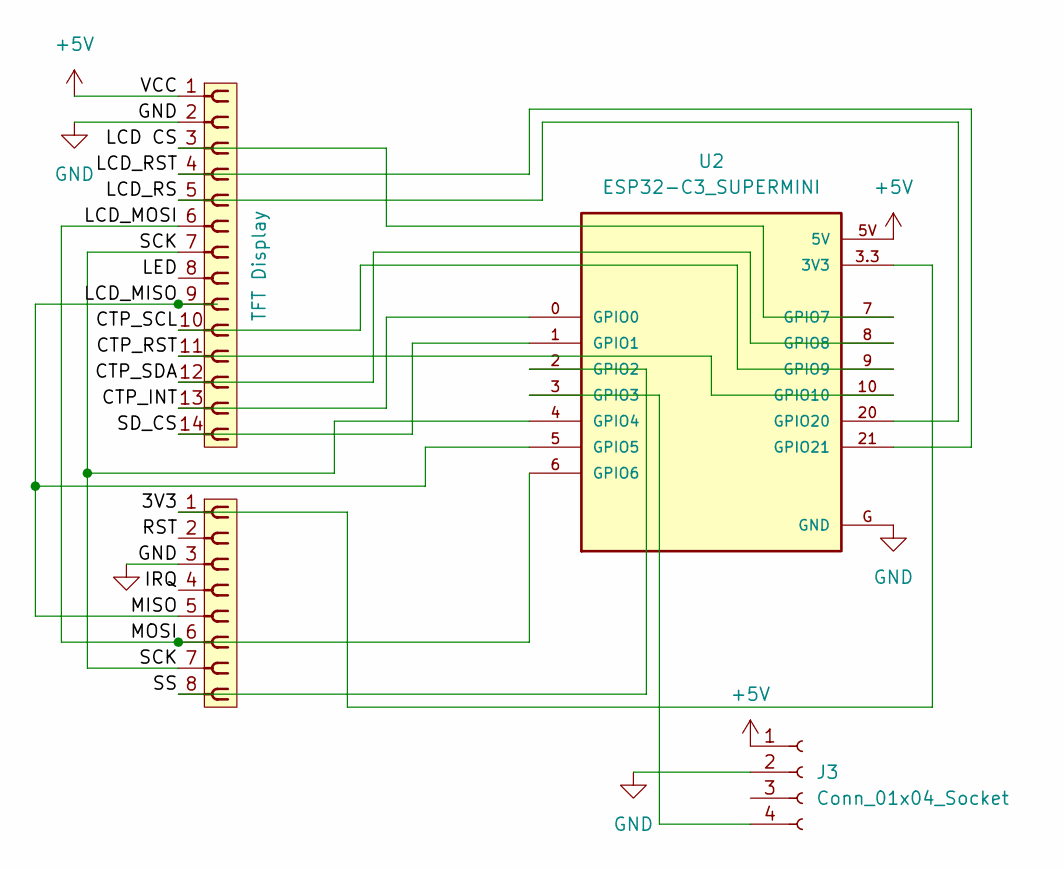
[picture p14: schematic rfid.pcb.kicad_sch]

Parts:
J1: TFT Display; PinSocket_1x14_P2.54mm_Vertical
J2: RFID Reader; PinSocket_1x08_P2.54mm_Vertical
J3: Conn_01x04_Socket; PinSocket_1x04_P2.54mm_Vertical
U2: ESP32-C3_SUPERMINI; MODULE_ESP32-C3_SUPERMINI

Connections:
+5V: J1.1, J3.1, U2.5V
/3V3: J2.1, U2.3.3 (3V3)
/CTP_INT: J1.13, U2.0 (GPIO0)
/CTP_RST: J1.11, U2.10 (GPIO10)
/CTP_SCL: J1.10, U2.9 (GPIO9)
/CTP_SDA: J1.12, U2.8 (GPIO8)
/IRQ: J2.4
/LCD CS: J1.3, U2.7 (GPIO7)
/LCD_MISO: J1.9, J2.5, U2.5 (GPIO5)
/LCD_MOSI: J1.6, J2.6, U2.6 (GPIO6)
/LCD_RS: J1.5, U2.20 (GPIO20)
/LCD_RST: J1.4, U2.21 (GPIO21)
/LED: J1.8
/RST: J2.2
/SCK: J1.7, J2.7, U2.4 (GPIO4)
/SD_CS: J1.14, U2.1 (GPIO1)
/SS: J2.8, U2.2 (GPIO2)
GND: J1.2, J2.3, J3.2, U2.G (GND)
unnamed: J3.4, U2.3 (GPIO3)

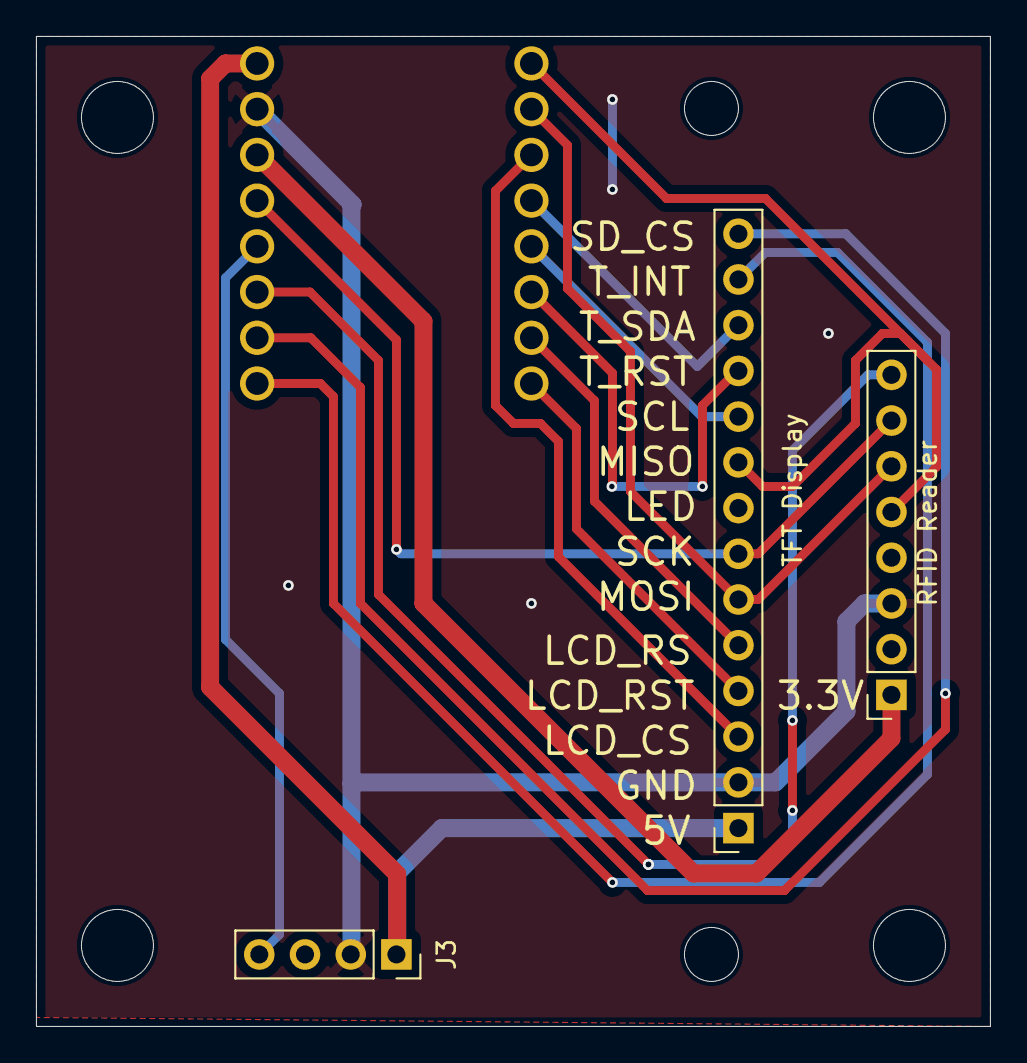
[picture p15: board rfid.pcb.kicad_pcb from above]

Board: 2 copper layers, 53.0 x 55.0 mm, 4 parts (1 on the bottom side), 16 nets.

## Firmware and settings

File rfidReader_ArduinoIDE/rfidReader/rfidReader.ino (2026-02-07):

/*     
 * -----------------------------------------------------------------------------------------
 * This program shall be used to handle the following use cases
 * 1.) Counter                                                                           Implemented
 *     The assistant at the counter read the rfid number of the tag and place 
 *     it to a database table in combination with the customer number field
 *     which is also used for union members of the open workshop
 * 2.) SwitchBox                                                                         Implemented
 *     The customer can switch the power of the requested machine on,
 *     when he has joined the introduction course of this machine.
 *     in a database this is mentioned, and part of the answer of the server.
 * 3.) GateKeeper                                                                        Implemented
 *     Set the start and end signal in the database table, when the customer or
 *     union member of the open workshop enter or leave the workshop area.
 * 4.) AddTag                                                                            Implemented
 *     All rfid numbers shall be registered in advance, 
 *     that the edge SW on the server can handle this situation, this use case was introduced
 * Hint:
 * -) The code is splitted to several files to have shorter files which provide 
 *    a better overview
 *
 * https://github.com/OSSLibraries/Arduino_MFRC522v2#pin-layout           -- RFID-Modul
 *
 * https://github.com/espressif/arduino-esp32/tree/master                 -- HTTPClient Library
 * https://arduinojson.org/?utm_source=meta&utm_medium=library.properties -- JSON Library  
 */

//-----------------------------
// 
//  pin def of the used setup  
//  BREADBOARD - when you use the breadboard
//  PCB        - when you use the 1st version of the PCB
//
//  with the current pcb version 2024 the rfid reader can be placed on the left or on the right side
//  so the orientation of the TFT display is to set,
//  with the parameter RFIDREADERRIGHT the pins of the TFT display are on the right side 
//  and the rfid reader is on the right side of the TFT display

//#define BREADBOARD          // ESP32 Dev Module
#define PCB                 // ESP32 C3 on PCB
#define RFIDREADERRIGHT     // processor settings are to modify

// The used pins of this project are defined in the pinoutdef.h file
// the PCB version use a ESP32 C3 for te Arduino IDE the processor def is to set to ESP32C3 Dev Module
// breadboard is using the setting ESP32 Dev Module
// also the serial interface is to set 

#include <esp_sleep.h>
#include <Arduino.h>

#include <WiFi.h>
#include <esp_wifi.h> // get the mac address
#include <HTTPClient.h>

#define wifiNoTries 50      // number of tries to get WLan connection

//-----------------------------
#include <MFRC522v2.h>
#include <MFRC522DriverSPI.h>
#include <MFRC522DriverPinSimple.h>
#include <MFRC522Debug.h>
//-----------------------------
#include <ArduinoJson.h>        // the json format shall be used to to cut out the
                                // value of a property from the set of transferred data
//-----------------------------
#include <ESP32Time.h>          // https://github.com/fbiego/ESP32Time
//----------------------------- 
#include <Adafruit_GFX.h>
#include <SPI.h>
#include <Wire.h>
#include <Adafruit_ILI9341.h>

#include <SdFat.h>                // SD card &amp; FAT filesystem library
#include <Adafruit_SPIFlash.h>    // SPI / QSPI flash library
#include <Adafruit_ImageReader.h> // Image-reading functions

#include "RAK14014_FT6336U.h"     // Click here to get the library: http://librarymanager/All#RAK14014_FT6336U

// #include "pitches.h"  def of tones
#include "pinoutdef.h"
#include "ver.h"

#include "netcred.h"              // WLan-Zugangs bzw. Server-Information

#define RawComFlag  0          // 1 <= der rfidReaader sendet ein RawPaket, 0 <= der rfidReader sendet http-Anfragen an den Server
bool bSleepMode  = false;

bool bWifiInitFlag = false;
bool bWifiLostFlag = false;

HTTPClient httpClient;  // to send the control command to the shelly or similar device
WiFiClient wifiClient;  // for discussion with the server and database

uint8_t uiUpdatedUC = 0;
uint8_t uiUpdatedRFID = 1;

// http://192.168.8.151/relay/0?turn=off
String strDevName         = "SchaffBar-RFID-Controller";
String strDevUseCase      = String(" "); // SwitchBox Ein/Ausschalten von Geräten - TimeCtrl Betreten/Verlassen des Werkstatt-Bereichs - Counter
String strHTTPstart       = "http://";
String strIpAddrSolenoid  = "192.168.8.151";
String strSolenoidOff     = "/relay/0?turn=off";
String strSolenoidOn      = "/relay/0?turn=on";
String strSolenoidToggle  = "/relay/0?turn=toggle";

String strSalut           = "Hi/Bye";
String strCustName        = "XXXXXXXXXXX";
String strStartEnd        = "StartStop";
String strCustomerTime    = "XX:XX";       // answer from server XX:XX for start and XX:XX - YY:YY for stop
String strIcon            = "";
String strUnits           = "ZZZZZZ";      // usecase SwitchBox
String strError           = "";
String strFlagOK          = "";            // OK - access to tool granted / KO - access of tool not allowed

// the following variables are used to display the good-bye message for the usecase "SwitchBox"
String strWorkID          = "";            // store the card id that nobody else can switch off the machine
String strWorkStartTime   = "";            // Start-Zeitstempel vom ESP32 bestimmt
String strWorkEndTime     = "";            // Stop-Zeitstemper vom ESP32 bestimmt 
String strWorkUnitMin     = "";
String strWorkUnitSec     = "";
bool bDsplySwitchBoxInit  = false;

String strHeader          = "";
String strMsg             = "";
int iIconNo               = 0;

String strTerminal        = "";             //  Terminal ID, where the RFID-Reader is connected 

//-------------------------------------------------------------
ESP32Time rtc(0);  // possible offset in seconds

int     iLastTime       = 0;
int     iCountSec       = 0;
int     iCountMin       = 0;
int     iCountHour      = 0;
int     iCountDay       = 0;
int     iUnitLengthMin  = 0;
int     iUnitLengthHour = 0;
int     iUnitLengthDay  = 0;
int     iUnitCountMin   = 0;
int     iUnitCountHour  = 0;
int     iUnitCountDay   = 0;


uint8_t uiFlagRunTimer  = 0;
typedef struct 
{
  uint    uiDateYear      = 0;
  uint8_t uiDateMonth     = 0;
  uint8_t uiDateDay       = 0;
  uint8_t uiDateHour      = 0;
  uint8_t uiDateMinute    = 0;
  uint8_t uiDateSecond    = 0;
  uint8_t uiFlagValid     = 0;
} timeproj_t;

timeproj_t sTimeRunning;
timeproj_t sTimeStart;

//----------------------------------------------------

float fSolUnitsMillis = 0.0;
float fSolUnitsMin    = 0.0;

uint8_t  uiUnitSeconds       = 0;     // seconds of the interval used for use case 
long int liUnitMinutes       = 0;     // minutes of the interval
long int liUnitCounterMil    = 0;     // millis counter to check the intervall
//uint8_t  uiGKLastSecond   = 0;     // update of seconds from the rtc clock library
//bool     bGKMinUpdateFlag = false; // update the minute value on the display
bool     bUnitRun            = false;
bool     bUnitMinInitDisplay = false;
int iOldXPos = 0;
int iOldYPos = 0;
String strOldTxt = "";

//----------------------------------------------------

String strUseCaseName[7] = {"GetInit","Switchbox","GateKeeperIn","GateKeeperOut","Counter","AddTag","Unknown"};
// das Feld UseCase wird auf dem Server auf Type geändert werden
typedef enum eDevUseCase_t      
{
  GetInit,       // request for init data
  SwitchBox,     // is switching the different tools on and off
  GateKeeperIn,  // starts the timer 
  GateKeeperOut, // stops the timer 
  Counter,       // support the hero at the counter
  AddTag,        // add tag to the card table, to create a closed pool of tags
  UnKnown        // unkown use case
} eDevUseCase_t;

String strRouteInit    = "/device/init";       // Für die Anmeldung des rfidReaders am Server, wird verwendet für den UseCase GetInit
String strRouteCounter = "/device/counter";    // Für Aktionen am Counter, wird verwendet für die UseCase AddTag und Counter
String strRouteCard    = "/device/card";       // Für Kundenaktionen am rfidReader für die UseCases GateKeeper und SwitchBox

eDevUseCase_t eUC= GetInit;

typedef enum eDevState_t
{
  error,
  start,
  idle,
  working,
  end                   // temporary state, when a "good bye" message shall be displayed, after an intervall the rfid reader shall fall back to idle mode
} eDevState_t;

eDevState_t eState = start;

typedef enum eSolenoidState_t
{
  SolenoidOn,
  SolenoidOff
} eSolenoidState_t;

eSolenoidState_t eSolState = SolenoidOff;

typedef struct 
{ // shall be used for point or dimensions of a square for width and hight
  int x;  // x-position
  int y;  // y-position
  int w;  // width of the text box
  int h;  // height of the text box
} sQdrupel;

#define brightgreen 0xEFBA
#define green 0x8574

//----------------------------------------
MFRC522DriverPinSimple ss_pin(Pin_MFRC522_CS); // Create pin driver. See typical pin layout above.

SPIClass &spiClass = SPI; // Alternative SPI e.g. SPI2 or from library e.g. softwarespi.

const SPISettings spiSettings = SPISettings(SPI_CLOCK_DIV4, MSBFIRST, SPI_MODE0); // May have to be set if hardware is not fully compatible to Arduino specifications.

MFRC522DriverSPI driver{ss_pin, spiClass, spiSettings}; // Create SPI driver.

MFRC522 mfrc522{driver}; // Create MFRC522 instance.

//--------------------------
Adafruit_ILI9341 tft = Adafruit_ILI9341(TFT_CS, TFT_DC,TFT_RST);
//Adafruit_ILI9341 tft = Adafruit_ILI9341(spiClass, TFT_DC, TFT_CS, TFT_RST);
//--------------------------
FT6336U ft6336u;              // Touch object
static uint8_t iTouchIntStatus = false; // TP interrupt generation flag.
//--------------------------------------------------------------------------
// For SD card use, these two globals are declared:
SdFat SD; // SD card filesystem
Adafruit_ImageReader reader(SD); // Image-reader object, pass in SD filesys
uint8_t uiSDCardFlag = 0;

//---------------------------------------------------------------------------
String strUIdHex = "";
uint8_t uidLength = 0;
char chArCardID[30];
char chArCarIdLen[3];

const int cInitWaitTime          =  4000;  // How long the prog shall wait until the init of the touch unit is ready
const int cWaitForAnyTouch       =  5000;  // Waiting for Touch-Action or Timer expires
const int cGateKeeperDisplayTime =  3000;  // How long the salutaion and name shall be displayed on the tft
const int cWaitforSoftReset      = 15000;  // represent an error message then start again

//---------------------------
JsonDocument jsonSendDoc;   // String jsonSendData = "";
JsonDocument jsonRecDoc;    // String jsonReceiveData = "";

unsigned long ulTimeStart       = 0;  // Time stamp when the machine was enabled
unsigned long ulLocalEpochStart = 0;

unsigned long ulIdleStart       = 0;      // Start des Idle-Mode
unsigned long ulIdleMaxDuration = 360;    // Länge des Idle-Mode ohne Aktivität in sec

bool bIntChange  = false;  // flag to start display 
bool bIntRunning = false;  // intervall is running
long int lIntStartAt = 0;  // millis(), when the intervall was started
const long clIntDuration = 1000 * 15;  // duration how long the intervall shall run

void setup() 
/****************************************************************************************************
 * void setup() -Standard Init code of the sketch, consist of several init function of the different HW components
 *  TFT display
 *  Touch Unit
 *  Timer Functionality
 *  Wifi Functions
 ****************************************************************************************************/
{
  bool bWakeUpFlag = false;
  Serial.begin(115200); // Initialize serial communications with the PC for debugging.
  //while (!Serial);      // Do nothing if no serial port is opened (added for Arduinos based on ATMEGA32U4).
  Serial.println("Setup start ...");
  //bWakeUpFlag = checkWakeUp();
  //if (!bWakeUpFlag)
  //{
    initDisplay();
    initTouch();  // ToDo: add return value

    Serial.println(F("Scan PICC to see UID, SAK, type, and data blocks..."));
    mfrc522.PCD_Init();   // Init MFRC522 board.
    delay(10); // for is requested for slow ICs 
    MFRC522Debug::PCD_DumpVersionToSerial(mfrc522, Serial);	// Show details of PCD - MFRC522 Card Reader details.
    
    eState = start;

    //////////////////////////////////////////////  SD-Card
    if(!SD.begin(SD_CS, SD_SCK_MHZ(25))) 
    { // ESP32 requires 25 MHz limit
      Serial.println(F("SD begin() failed"));
      uiSDCardFlag = 0;
      //for(;;); // Fatal error, do not continue
    }
    else
    {
      Serial.println(F("SD begin() ok :-)"));
      uiSDCardFlag = 1;
    }
    ImageReturnCode stat;
    stat = reader.drawBMP("/logo.bmp", tft, 0, 0);
    dsplySWVersion();
    delay(4000);
    tft.fillScreen(ILI9341_BLACK);
    //stat = reader.drawBMP("/schwein.bmp", tft, 0, 0); //  
    //delay(4000);
    //tft.fillScreen(ILI9341_BLACK);
    Serial.flush();
    //////////////////////////////////////////////
    eUC = GetInit;
    initTime();
    initWifi();
    Serial.flush();
    jsonSendDoc = getJSONInitData();
    //ulLocalEpochStart = rtc.getLocalEpoch();
    //unsigned long xxx = millis();
    //playOK();
    //Serial.println("timediff = "+String(rtc.getLocalEpoch()-ulLocalEpochStart));
    //Serial.println("timediff = "+String(millis()-xxx));
    //Serial.println("+++++++++++++++++++++++++++++++");
    dsplyErrorInfo("Info","Lade Config Data", 1, 0, 4);
    #if RawComFlag == 1
          sendRequest(jsonSendDoc);
    #else
          sendHTTPRequest(strRouteInit,jsonSendDoc);
    #endif    
  //}
  if(eUC == SwitchBox)
  {
    // UseCase = SwitchBox -> Schalte das Relais aus
    SolenoidOFF();
  }
  bIntChange  = false;  // flag to start display 
  bIntRunning = false;  // time how long the message shall be displayed
  Serial.println("UseCase "+String(eUC));
  Serial.println("State   "+String(eState));
  dspClear();
  if((eUC != GetInit) and (eUC != UnKnown))
  {
    setIdleStart(); // eState = idle;
  }
  playOK();
  Serial.println("End of SetUp()");
  Serial.flush();
}

void loop() 
/****************************************************************************************************
 * void loop() - Standard Loop Function of the Sketch
 * To get the ID of the RFID-Tag
 * or user activations of the Touch Unit
 * The user actions will be evaluated in the associated sub-function
 ****************************************************************************************************/
{
	//if ( !mfrc522.PICC_IsNewCardPresent() || !mfrc522.PICC_ReadCardSerial()) {
	//	return;
	//}
  Serial.println("Start of Loop() - "+rtc.getTime()+" - State "+int(eState)+ " - UC - "+int(eUC));
  //if((eState == idle) or ((eState == working)))
  //{
    if((WiFi.status() == WL_CONNECTED)&&(bWifiInitFlag))
    {
    if(mfrc522.PICC_IsNewCardPresent() && mfrc522.PICC_ReadCardSerial())
    {
      MFRC522Debug::PICC_DumpToSerial(mfrc522, Serial, &(mfrc522.uid));
      Serial.println("RFID-ByteSize "+String(mfrc522.uid.size));
      Serial.println("RFID-ID "+Uid2StrHex(mfrc522.uid));
      uidLength = mfrc522.uid.size;
      strUIdHex = Uid2StrHex(mfrc522.uid); 
      strUIdHex.toCharArray(chArCardID, 26); 
      itoa(uidLength, chArCarIdLen, 10);
      Serial.println("UID-Len = "+ String(chArCarIdLen) + " / RFID-Tag " + String(chArCardID));
      // clear previous output
      //tft.fillRect(100,50,200,15,ILI9341_BLACK);
      // present card data on display
      //tft.setCursor(100,50);
      //tft.println(chArCarIdLen); 
      //tft.setCursor(130,50);
      //tft.println(chArCardID); 
      Serial.println("in loop() - "+getUseCase());
      if (eUC == SwitchBox)
      {
          Serial.println("evalSwitchBoxAction("+String(chArCardID)+"))");
          evalSwitchBoxAction(String(chArCardID));
      }
      else if ((eUC == GateKeeperIn) or (eUC == GateKeeperOut))
      {
        Serial.println("evalGateKeeperAction("+String(chArCardID)+"))");
        evalGateKeeperAction(String(chArCardID));
      }
      else if ((eUC == Counter) or (eUC == AddTag))
      {
        Serial.println("evalCounterAction("+String(chArCardID)+"))");
        evalCounterAction(String(chArCardID));   
      }
      else
      {
        // Init error message, this will be displayed in the next cycle of the loop
        eState = error;
        strMsg = "unknown Use Case detected!";
      }
    }
    if(iTouchIntStatus)
    { 
      iTouchIntStatus = false;
      Serial.print("FT6336U TD Status: "); 
      Serial.print(ft6336u.read_td_status());  
      //Serial.print("FT6336U Touch Event/ID 1: ("); 
      //Serial.print(ft6336u.read_touch1_event()); 
      //Serial.print(" / "); 
      //Serial.print(ft6336u.read_touch1_id()); 
      Serial.println(")"); 
      Serial.print("FT6336U Touch Position 1: ("); 
      Serial.print(ft6336u.read_touch1_x()); 
      Serial.print(" , "); 
      Serial.print(ft6336u.read_touch1_y()); 
      Serial.println(")"); 
      //Serial.print("FT6336U Touch Weight/MISC 1: ("); 
      //Serial.print(ft6336u.read_touch1_weight()); 
      //Serial.print(" / "); 
      //Serial.print(ft6336u.read_touch1_misc()); 
      //Serial.println(")"); 
      //Serial.print("FT6336U Touch Event/ID 2: ("); 
      //Serial.print(ft6336u.read_touch2_event()); 
      //Serial.print(" / "); 
      //Serial.print(ft6336u.read_touch2_id()); 
      //Serial.println(")"); 
      //Serial.print("FT6336U Touch Position 2: ("); 
      //Serial.print(ft6336u.read_touch2_x()); 
      //Serial.print(" , "); 
      //Serial.print(ft6336u.read_touch2_y()); 
      //Serial.println(")"); 
      //Serial.print("FT6336U Touch Weight/MISC 2: ("); 
      //Serial.print(ft6336u.read_touch2_weight()); 
      //Serial.print(" / "); 
      //Serial.print(ft6336u.read_touch2_misc()); 
      //Serial.println(")"); 
      evalTouchAction();
    }  // end of touch action

    //}    // end of WLAN ok
  }
  if(eState == idle)
  {
    Serial.println("dsplyIdle()");
    dsplyIdle();
    if (bSleepMode)
    {
      //checkIdleDuration();
      // Ist nicht getestet und herunter priorisiert,
      // daher auskommentiert
    }
  }
  if(eState == working)
  {
    dsplyMask();
  }
  if(eState == error)
  {
    Serial.println("- error - "+strMsg);
    if(dsplyErrorInfo("Error",strMsg,5,1,99))
    { // touch event occured => soft reset
      softReset();
    }    
    delay(500);
    Serial.println("- error - "+strMsg);
  }
  if(eState == end)
  {
    Serial.println("intermediate display - eState = end");
    if((bIntChange == true) and (bIntRunning == false))
    {
      
      bIntChange  = false;  // flag to start display 
      bIntRunning = true;  // time how long the message shall be displayed
      lIntStartAt = millis();  // get start point f the intervall
      dsplyErrorInfo(strHeader,strMsg,0,0,iIconNo); 
      Serial.println("- End-Flag received - "+strMsg);
      Serial.println("- Header - "+strHeader); 
      Serial.println("- Msg    - "+strMsg);
      Serial.println("- Icon   - "+String(iIconNo));
      dsplyPrepareTouchEvent();
    }
    dsplyTime();
    dsplyWifiState();
    if(((eUC == GateKeeperIn) or (eUC == GateKeeperOut))and ((iIconNo == 9)  or (iIconNo == 10)) or ((eUC == SwitchBox) and  (iIconNo == 10))) // and bGKMinUpdateFlag

    if((eUC == SwitchBox) and  (iIconNo == 10))
    { // the value of the units shall be displayed when the customer is entering or leving the workshop are every time
      // or switch of the tool 
      Serial.println("Info: before dsplyUnitSecond() ");
      dsplyUnitSecond();  // the update of minutes will called, when necessary
    }
    if(bIntRunning)
    {
      Serial.println("Start: "+String(lIntStartAt)+" Len "+String(clIntDuration)+" Time "+String(millis()));
      if(lIntStartAt + clIntDuration <= millis())
      { // message representation ends here
        Serial.println("Info: before chngState2Idle() ");
        chngState2Idle();
      }
    }
  }
  Serial.flush(); 
}

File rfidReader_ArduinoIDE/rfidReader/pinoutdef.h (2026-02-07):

/*
 * Hardware Description:
 * Typical pin layout used:
 * -----------------------------------------------------------------------------------------
 *             MFRC522      Arduino       Arduino   Arduino    Arduino          Arduino
 *             Reader/PCD   Uno/101       Mega      Nano v3    Leonardo/Micro   Pro Micro
 * Signal      Pin          Pin           Pin       Pin        Pin              Pin
 * -----------------------------------------------------------------------------------------
 * SPI SS      SDA(SS)      10            53        D10        10               10
 * SPI MOSI    MOSI         11 / ICSP-4   51        D11        ICSP-4           16
 * SPI MISO    MISO         12 / ICSP-1   50        D12        ICSP-1           14
 * SPI SCK     SCK          13 / ICSP-3   52        D13        ICSP-3           15
 *
 * The parameter BREADBOARD and PCB are defined in the main file of the project
 */
#ifdef BREADBOARD
  #define BUZZZER_PIN  12// ESP32 pin GPIO14 connected to piezo buzzer

  //------------------------------
  #define Pin_MFRC522_Reset  25 
  #define Pin_MFRC522_IRQ    26
  #define Pin_MFRC522_CS     2  

  //-----------------------------
  #define SD_CS   14  // SD card select pin

  #define TFT_CS   4
  #define TFT_DC  17
  #define TFT_RST 16

  //------ Touch Driver ------------------
  #define Touch_INT_PIN      0
  #define Touch_RST_PIN     15
  #define Touch_RST_Duration_ms 100
#endif

#ifdef PCB  
  #define BUZZZER_PIN  1 // ESP32 pin GPIO1 connected to piezo buzzer

  #define TFT_CS  7
  #define TFT_DC  20//17
  #define TFT_RST 21//16

  #define SD_CS   3
  //------------------------------
  #define Pin_MFRC522_Reset 25 // not used
  #define Pin_MFRC522_IRQ   26 // not used
  #define Pin_MFRC522_CS    2//27  

  //------ Touch Driver ------------------
  #define Touch_INT_PIN   0
  #define Touch_RST_PIN  10
  #define Touch_RST_Duration_ms 100
#endif

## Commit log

2025-03-24 Init
    Initialer Transfer der rfidReader Software
    hier fehlt noch der UseCase zum Schalten der Geräte und insgesamt ein intensiver Test
2025-03-24 update des Readme
2025-04-04 2. Version mit Löchern für das Display und GPIO1 nach SD_CS
    [rfid.pcb.kicad_pcb, rfid.pcb.kicad_pcb_bom.csv, rfid.pcb.kicad_pcb_positions.csv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]
2025-04-23 Bugfix -> Update V 0.1.1
    Tippfehler mit grober Auswirkung beseitigt
    -) in der Datei support.ino in der Funktion void evalTouchAction() = ersetzt durch ==
    und ebenfalls den UseCase Counter hinzugefügt
    -) in weiteren Dateien zusätzliche Serial.prints hinzugefügt die ich zu Debug-Zwecken noch behalten möchte
    [display.ino, rfidReader.ino, support.ino]
2025-05-09 verwendete Bibliotheken für die Arduino IDE
    hier befinden sich alle verwendeten Bibliotheken mit ihren weiteren Abhängigkeiten
    [Arduino-Uno-r3-with-RFID-RC522.fzz, CPPLINT.cfg]
2025-06-14 ESP32 Update auf V 0.2.0 - UseCase SwitchBox implementiert
    Der UseCase zum Ein- und Ausschalten der verschiedenen Werkzeuge
    mittels eines WLan-Relais wurde implementiert.
2025-07-17 ESP32 Update V0.3.1 UseCase AddTag hinzugefügt
2025-07-17 TimeMachine Update zu ESP32 ArduinoIDE V 0.3.1
2025-07-18 ESP32 Update V0.3.2 UseCase AddTag Bildbewechsel im Idle State berichtigt
2025-07-19 ESP32 Update V0.3.3 Separierung der Zugangsdaten
2025-08-06 ESP32 Update HTTP communication
